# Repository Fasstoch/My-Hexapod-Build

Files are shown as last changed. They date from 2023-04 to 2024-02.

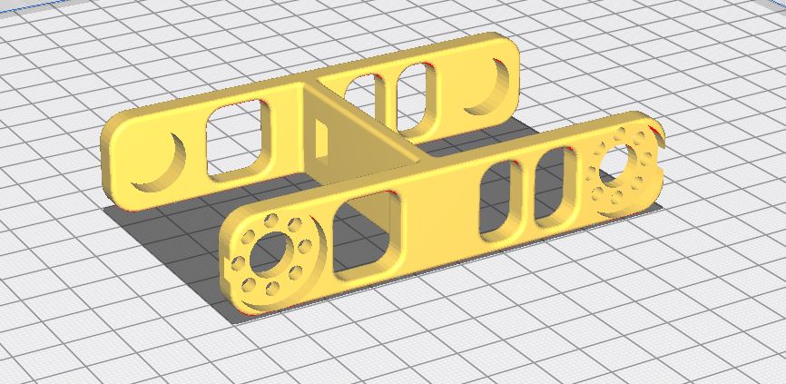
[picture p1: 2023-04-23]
Images/Femur.JPG

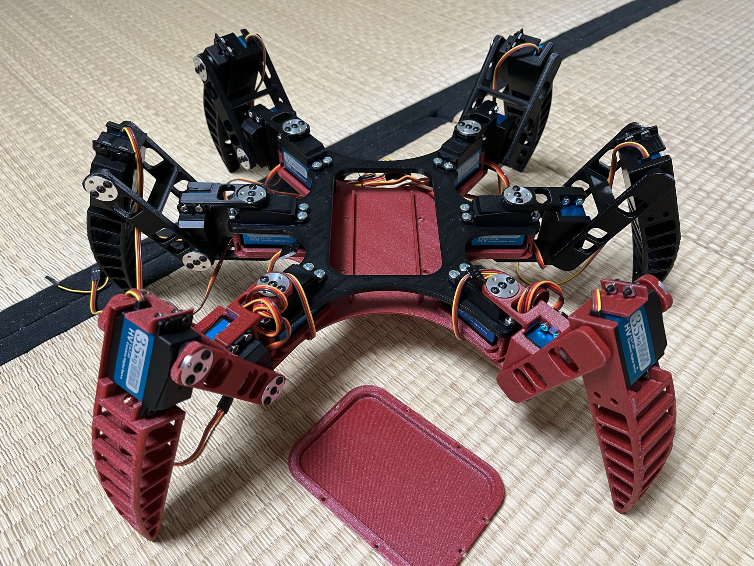
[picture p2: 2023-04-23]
Images/MyPLAHexapod.jpeg

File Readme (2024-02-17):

Readme File :

This 3D design is made to be compliant with standard servo like these : 
https://fr.aliexpress.com/item/1005004291650317.html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

This 3D design is made to be compliant with metal circle horns (25 T Servo / diam 20mm) like these : 
https://fr.aliexpress.com/item/4000600375910.html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

This 3D design is made to be compliant with bearings (4 mm x 13 mm x 5 mm) like these : 
https://www.amazon.fr/dp/B07FXXMN4P?psc=1&ref=ppx_yo2ov_dt_b_product_details

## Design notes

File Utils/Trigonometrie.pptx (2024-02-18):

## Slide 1

hexapod_spiderbot_tutorials (https://github.com/robs-tech-workbench/hexapod_spiderbot_tutorials/blob/main/tutorial_forward_kinematics/media/top_view.png)/ (https://github.com/robs-tech-workbench/hexapod_spiderbot_tutorials/blob/main/tutorial_forward_kinematics/media/top_view.png)tutorial_forward_kinematics (https://github.com/robs-tech-workbench/hexapod_spiderbot_tutorials/blob/main/tutorial_forward_kinematics/media/top_view.png)/media/top_view.png at main · robs-tech- (https://github.com/robs-tech-workbench/hexapod_spiderbot_tutorials/blob/main/tutorial_forward_kinematics/media/top_view.png)workbench (https://github.com/robs-tech-workbench/hexapod_spiderbot_tutorials/blob/main/tutorial_forward_kinematics/media/top_view.png)/ (https://github.com/robs-tech-workbench/hexapod_spiderbot_tutorials/blob/main/tutorial_forward_kinematics/media/top_view.png)hexapod_spiderbot_tutorials (https://github.com/robs-tech-workbench/hexapod_spiderbot_tutorials/blob/main/tutorial_forward_kinematics/media/top_view.png) · GitHub (https://github.com/robs-tech-workbench/hexapod_spiderbot_tutorials/blob/main/tutorial_forward_kinematics/media/top_view.png)

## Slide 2

Top

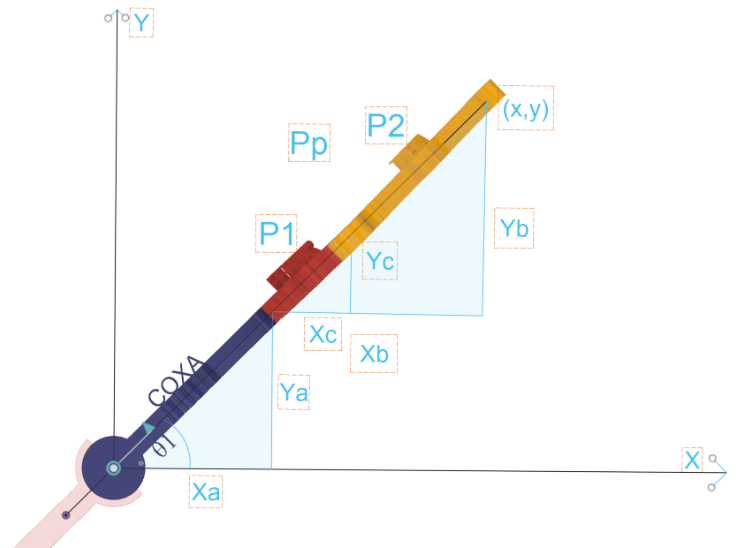
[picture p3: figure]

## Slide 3

Side

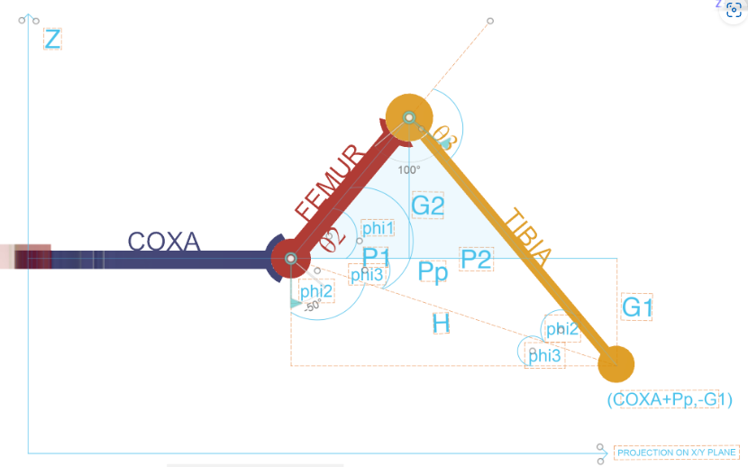
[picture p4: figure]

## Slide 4

3D

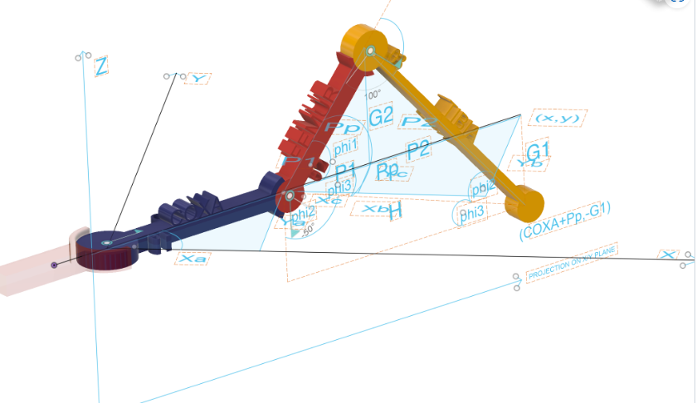
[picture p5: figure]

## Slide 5

sin ( θ )= (opp)/(hyp) θ = arcsin((opp)/(hyp))
cos ( θ )= (adj)/(hyp) θ = arccos((adj)/(hyp))
tan ( θ )= (opp)/(adj) θ = arctan((opp)/(adj))

hyp

opp

θ

adj

A

cos ( C )= (a^2 +b^2 −c^2)/(2 ∗a ∗b)
cos ( A )= (b^2 +c^2 −a^2)/(2 ∗b ∗ c)
cos ( B )= (c^2 +a^2 − b^2)/(2 ∗c ∗a)

C=?

B

C

a

b

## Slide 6

1. Angle Conversion: The method begins by converting the joint angles from degrees to radians. This conversion is essential as trigonometric functions in Python's math library require angles in radians.
theta1, theta2, theta3 = map(math.radians, self.get_angles())
2. Coxa-Femur Joint Calculation:
  - Xa and Ya determine the x and y coordinates of the coxa-femur joint (the hip joint). They are calculated using the cosine and sine of theta1, respectively, multiplied by the length of the coxa (self.COXA). Cosine gives the horizontal component, and sine provides the vertical component.
Xa = self.COXA * math.cos(theta1)
Ya = self.COXA * math.sin(theta1)
3. Femur Segment Calculations:
  - The vertical component G2 of the femur length is calculated by the femur length (self.FEMUR) multiplied by the sine of theta2. This gives the vertical displacement.
  - The horizontal component P1 is found by multiplying the femur length by the cosine of theta2. This gives the horizontal displacement.
G2 = math.sin(theta2) * self.FEMUR
P1 = math.cos(theta2) * self.FEMUR
4. Femur-Tibia Joint Calculation:
  - Xc and Yc are the x and y coordinates of the femur-tibia joint (knee joint), computed by multiplying P1 with the cosine and sine of theta1.
Xc = math.cos(theta1) * P1
Yc = math.sin(theta1) * P1

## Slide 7

5.Tibia-Tip Joint Calculation:
  - This step involves calculating the position of the tibia-tip joint (foot of the leg) using a series of trigonometric calculations.
  - H is the straight-line distance from the femur-tibia joint to the tibia-tip joint, calculated using the Law of Cosines.
H = math.sqrt(self.TIBIA**2 + self.FEMUR**2 - 2*self.TIBIA*self.FEMUR*math.cos(math.radians(180) - theta3))
  - phi1 is calculated using the Law of Cosines again, to find the angle at the femur-tibia joint.
phi1 = math.acos((self.FEMUR**2 + H**2 - self.TIBIA**2) / (2*self.FEMUR*H))
  - phi2 is the angle at the tibia-tip joint. It's calculated by subtracting phi1 and the external angle ( 180^\circ - \theta3 ) from 180 degrees.
  - phi3 is an auxiliary angle, used to find the horizontal and vertical projections. It's calculated by subtracting theta2 from phi1.
phi2 = math.radians(180) - (math.radians(180) - theta3) - phi1
phi3 = phi1 - theta2
  - Pp is the horizontal projection of the tibia-tip joint on the plane of the femur. It is calculated using the cosine of phi3 multiplied by H.
Pp = math.cos(phi3) * H
  - P2 is the horizontal distance between the femur-tibia joint and the tibia-tip joint. It is calculated as the difference between Pp and P1.
P2 = Pp - P1
  - Yb and Xb are the x and y coordinates of the tibia-tip joint, calculated by multiplying the sine and cosine of theta1 by Pp, respectively.
Yb = math.sin(theta1) * Pp
Xb = math.cos(theta1) * Pp
  - G1 is the vertical component (z-coordinate) of the tibia-tip joint. It is calculated using the sine of phi3 multiplied by H. The result is negated as the z-axis might be defined downwards in the robot's coordinate system.
G1 = math.sin(phi3) * H
G1 = -G1
6.Joint Locations List:
  - The method concludes by creating a list of joint locations. Each joint location is represented by a set of x, y, and z coordinates. This list includes the positions of the base joint, coxa-femur joint, femur-tibia joint, and the tip of the leg.
joint_locations = [
[0, 0, 0], # Base joint
[Xa, Ya, 0], # Coxa-femur joint
[Xa + Xc, Ya + Yc, G2], # Femur-tibia joint
[Xa + Xb, Ya + Yb, G1] # Tip of the leg
]

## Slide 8

sin ( θ )= (opp)/(hyp) θ = arcsin((opp)/(hyp))
cos ( θ )= (adj)/(hyp) θ = arccos((adj)/(hyp))
tan ( θ )= (opp)/(adj) θ = arctan((opp)/(adj))

hyp

opp

θ

adj

A

cos ( C )= (a^2 +b^2 −c^2)/(2 ∗a ∗b) C =arccos ((a^2 +b^2 −c^2)/(2 ∗a ∗b) )
cos ( A )= (b^2 +c^2 −a^2)/(2 ∗b ∗ c)
cos ( B )= (c^2 +a^2 − b^2)/(2 ∗c ∗a)

C=?

B

C

a

b

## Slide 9

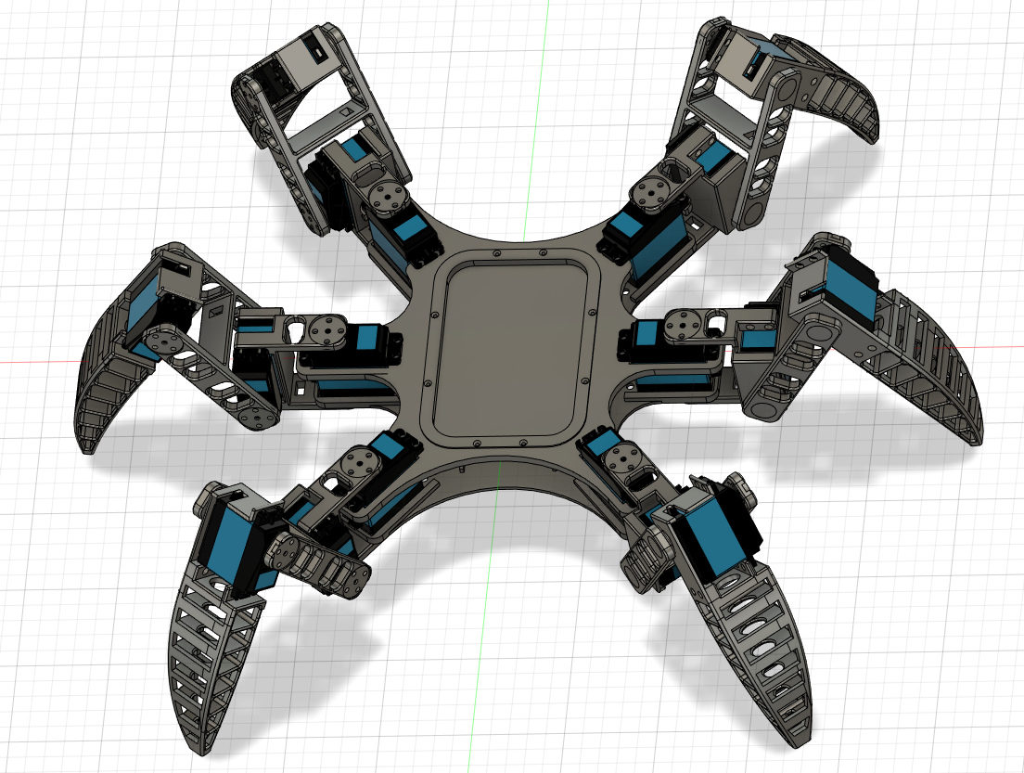
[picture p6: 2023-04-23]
Images/Fusion360View.png

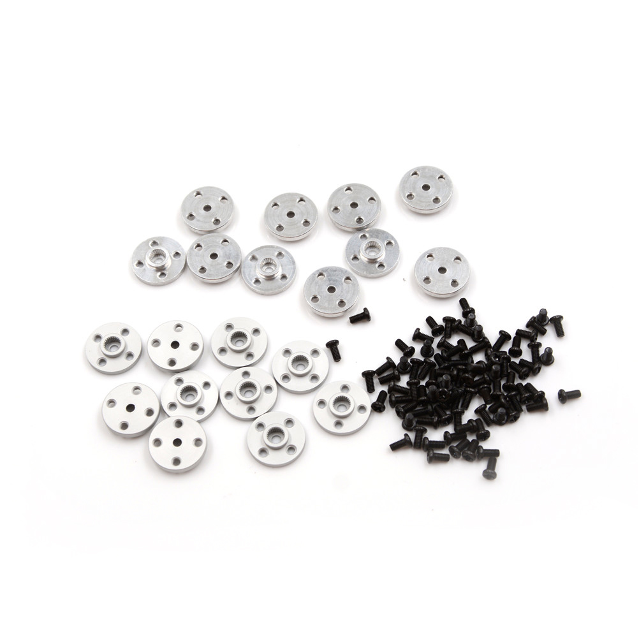
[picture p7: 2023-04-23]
Circle_metal_horn.jpg

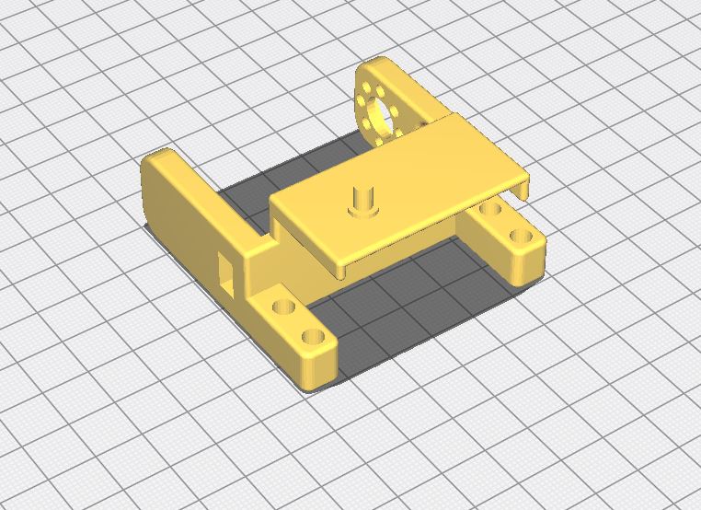
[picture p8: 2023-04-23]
Images/Coxa.JPG

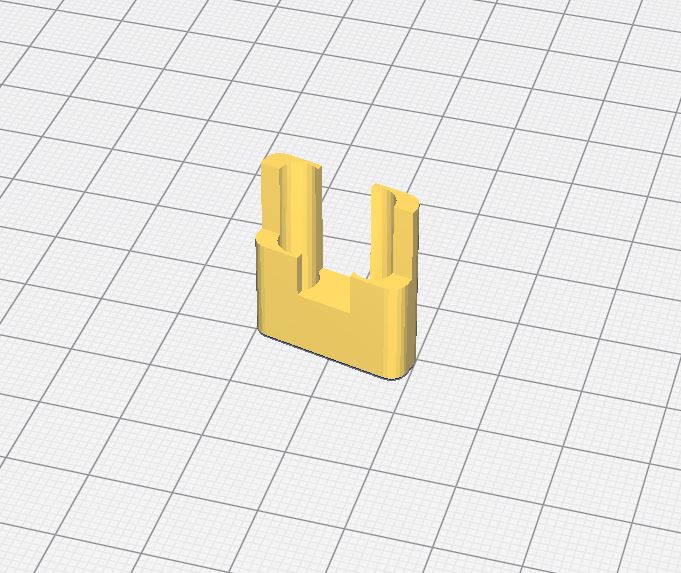
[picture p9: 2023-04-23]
Images/Spacer2.JPG

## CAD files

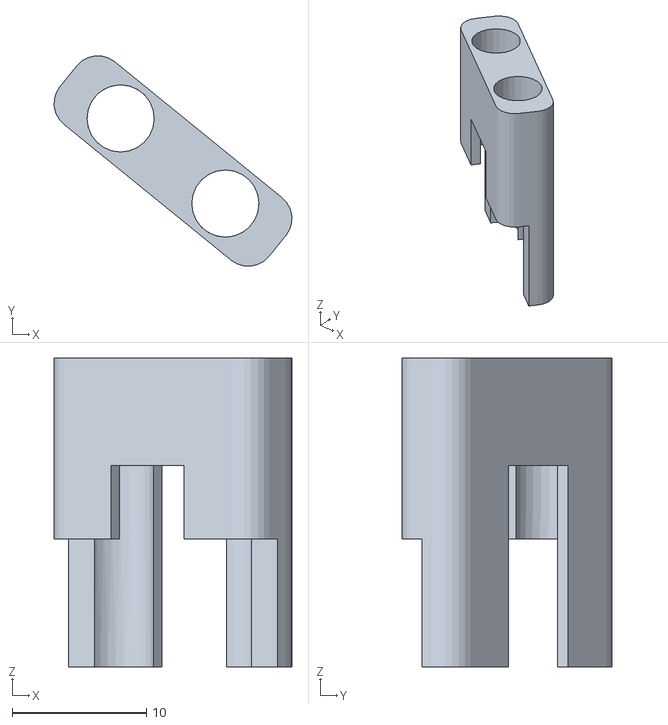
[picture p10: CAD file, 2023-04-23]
STL/Hexapod Reboot Spacer2.stl
17.7 x 15.7 x 23.0

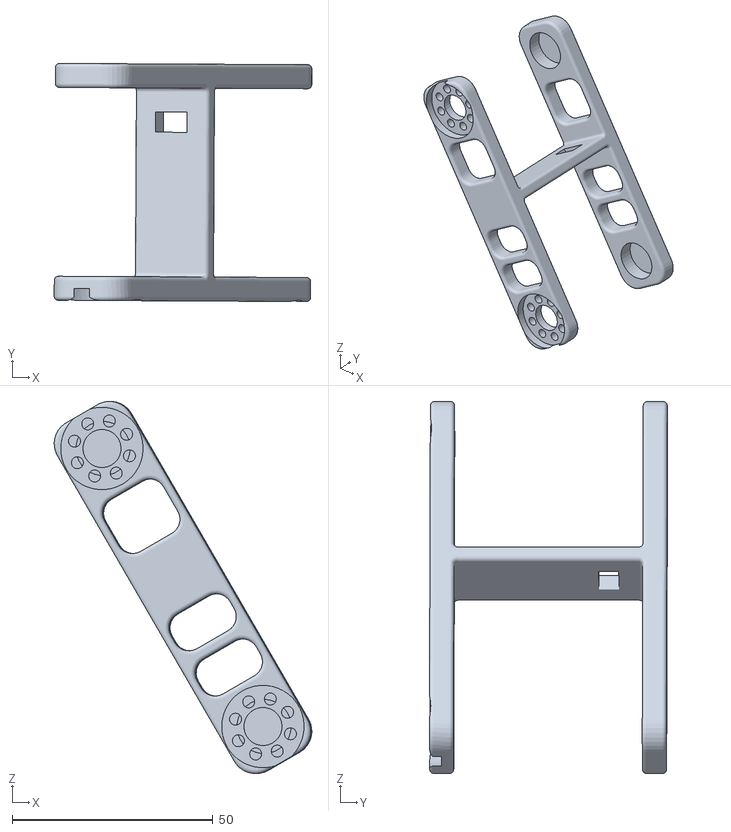
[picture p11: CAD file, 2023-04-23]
STL/Hexapod Reboot Femur.stl
64.2 x 59.3 x 92.6

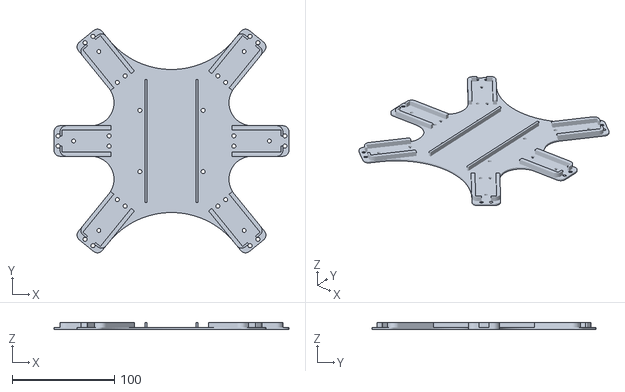
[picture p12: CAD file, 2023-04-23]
STL/Hexapod Reboot Body bottom.stl
230.0 x 218.9 x 7.00

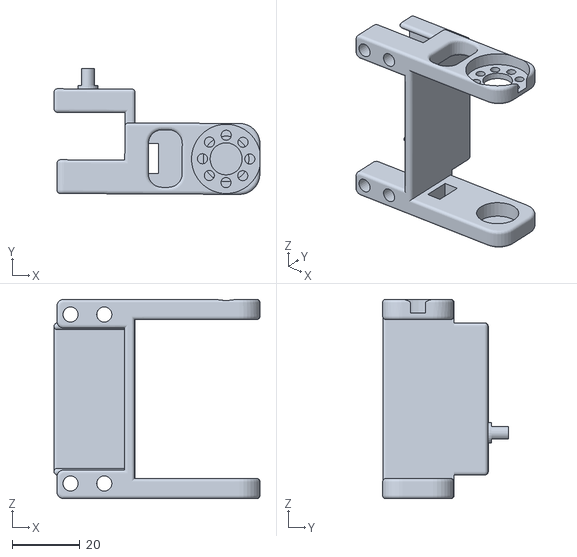
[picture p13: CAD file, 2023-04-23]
STL/Hexapod Reboot Coxa.stl
60.9 x 37.2 x 59.0

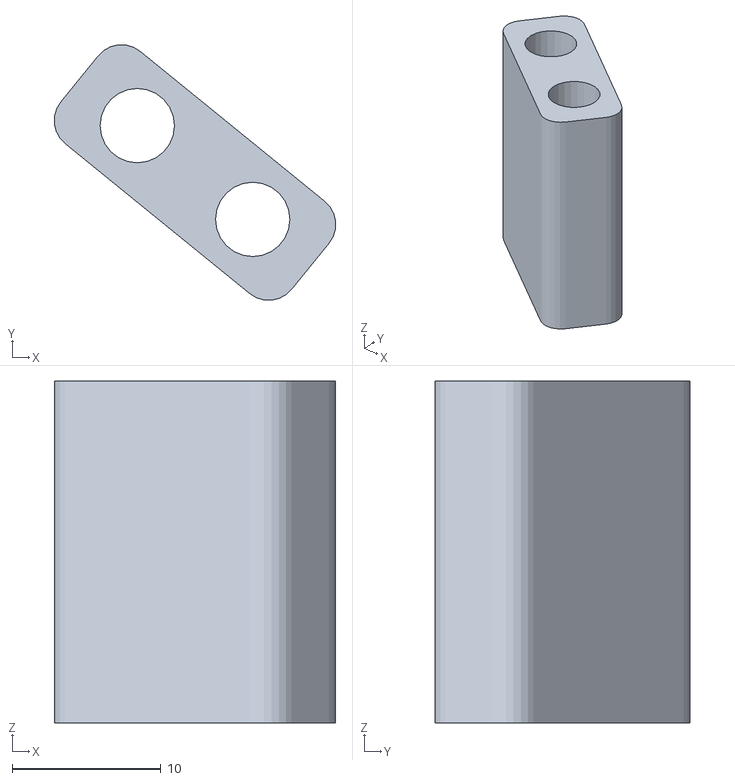
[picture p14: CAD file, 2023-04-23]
STL/Hexapod Reboot Spacer.stl
18.9 x 17.2 x 23.0

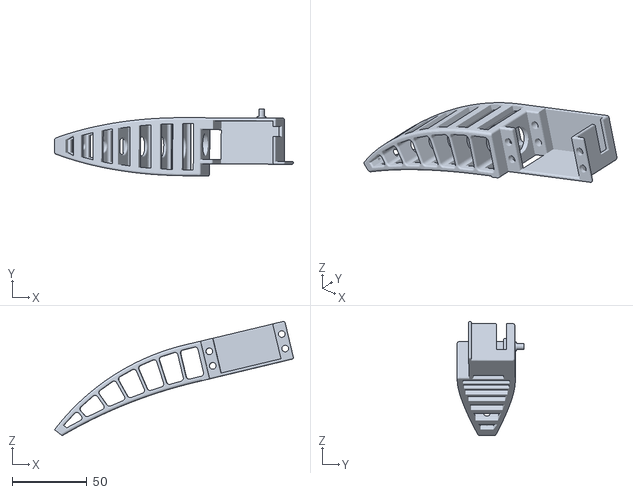
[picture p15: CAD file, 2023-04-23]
STL/Hexapod Reboot Tibia.stl
160.3 x 44.8 x 76.6

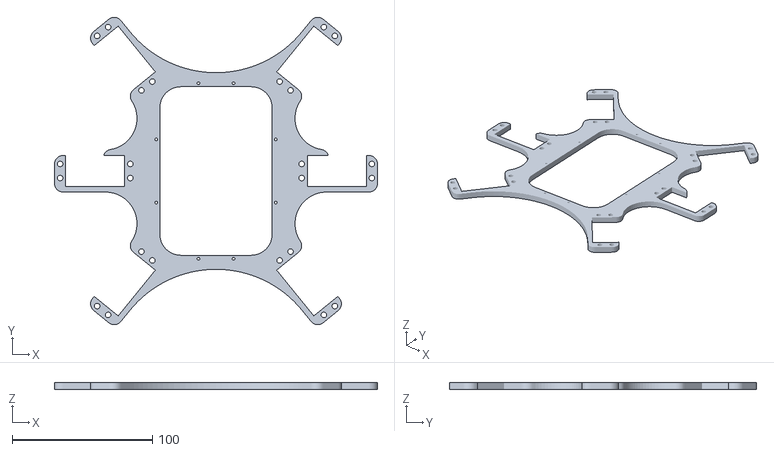
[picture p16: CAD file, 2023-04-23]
STL/Hexapod Reboot Body Top.stl
230.0 x 218.9 x 5.00

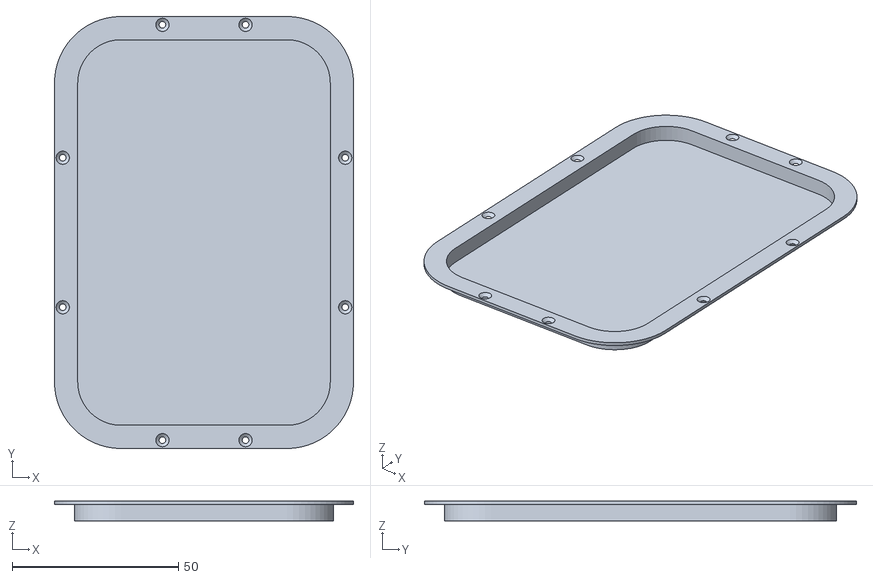
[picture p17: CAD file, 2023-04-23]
STL/Hexapod Reboot Support elec.stl
90.0 x 130.0 x 6.00

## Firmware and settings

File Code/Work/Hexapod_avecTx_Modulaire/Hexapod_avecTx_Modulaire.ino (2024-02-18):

// Appuie Gauche de la télécommande permet de switcher entre la position initiale et la position cible

#include "espNowCommunication.h"
#include "ServoConfig.h"
#include "ServoFunctions.h"
#include "gestionEtat.h"
#include "Angles.h"

void setup() {
  // Initialisation
  Serial.begin(115200);
  initialiserESPNow(); // défini dans "espNowCommunication.h", pour établir la communication avec l'ESP32 de la télécommande
  
  setupServos(); // défini dans "ServoConfig.h", pour initialiser les PIN, les SERVOMIN et SERVOMAX
  MoveLegInit(); // défini dans "ServoFunctions.h"

}

void loop() {
  gestionEtat(); // défini dans "gestionEtat.h"
  //delay(50);

}

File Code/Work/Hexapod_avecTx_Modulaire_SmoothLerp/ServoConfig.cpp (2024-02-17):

#include "ServoConfig.h"

Adafruit_PWMServoDriver board_left = Adafruit_PWMServoDriver(0x40);
Adafruit_PWMServoDriver board_right = Adafruit_PWMServoDriver(0x41);

// Define servos ports
uint8_t LegRF[3] = {15, 14, 13}; // Leg Right Front (0-180): Coxa(forward-backward) Femur(up-down) Tibia(down-up)
uint8_t LegR[3] = {10, 9, 8}; // Leg Right  (0-180): Coxa(forward-backward) Femur(up-down) Tibia(down-up)
uint8_t LegRB[3] = {2, 1, 0}; // Leg Right Back (0-180): Coxa(forward-backward) Femur(up-down) Tibia(down-up
uint8_t LegLF[3] = {0, 1, 2}; // Leg Left Front (0-180): Coxa(forward-backward) Femur(up-down) Tibia(down-up)
uint8_t LegL[3] = {5, 6, 7}; // Leg Left  (0-180): Coxa(forward-backward) Femur(up-down) Tibia(down-up)
uint8_t LegLB[3] = {13, 14, 15}; // Leg Left Back (0-180): Coxa(forward-backward) Femur(up-down) Tibia(down-up)

// Define servos MIN and MAX positions
int LegRF_SERVOMIN[3] = {160,210,150}; // Leg Right Front : Coxa, Femur, Tibia / 'minimum' pulse length count (out of 4096)
int LegRF_SERVOMAX[3] = {640,560,410}; // Leg Right Front : Coxa, Femur, Tibia / 'maximum' pulse length count (out of 4096)
int LegR_SERVOMIN[3] = {170,210,120}; // Leg Rightft : Coxa, Femur, Tibia / 'minimum' pulse length count (out of 4096)
int LegR_SERVOMAX[3] = {610,560,380}; // Leg Right : Coxa, Femur, Tibia / 'maximum' pulse length count (out of 4096)
int LegRB_SERVOMIN[3] = {180,230,100}; // Leg Right Back : Coxa, Femur, Tibia / 'minimum' pulse length count (out of 4096)
int LegRB_SERVOMAX[3] = {610,580,370}; // Leg Right Back : Coxa, Femur, Tibia / 'maximum' pulse length count (out of 4096)
int LegLF_SERVOMIN[3] = {150,215,120}; // Leg Left Front : Coxa, Femur, Tibia / 'minimum' pulse length count (out of 4096)
int LegLF_SERVOMAX[3] = {650,570,400}; // Leg Left Front : Coxa, Femur, Tibia / 'maximum' pulse length count (out of 4096)
int LegL_SERVOMIN[3] = {250,205,120}; // Leg Left : Coxa, Femur, Tibia / 'minimum' pulse length count (out of 4096)
int LegL_SERVOMAX[3] = {600,560,400}; // Leg Left : Coxa, Femur, Tibia / 'maximum' pulse length count (out of 4096)
int LegLB_SERVOMIN[3] = {130,205,130}; // Leg Left Back : Coxa, Femur, Tibia / 'minimum' pulse length count (out of 4096)
int LegLB_SERVOMAX[3] = {590,570,410}; // Leg Left Back : Coxa, Femur, Tibia / 'maximum' pulse length count (out of 4096)


void setupServos() {
  board_right.begin();
  board_left.begin();
  board_right.setPWMFreq(60);
  board_left.setPWMFreq(60);
}

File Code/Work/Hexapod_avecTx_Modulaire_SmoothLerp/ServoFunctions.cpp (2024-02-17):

#include "ServoFunctions.h"
#include "Angles.h"

float t = 0.0;

int angleToPulse(int ang, int SERVOMIN, int SERVOMAX) {
  int pulse = map(ang,0,180,SERVOMIN,SERVOMAX);
  return pulse;
}

void MoveLegInit(){
  for (int i=0; i<3; i++){
    board_right.setPWM(LegRF[i], 0, angleToPulse(initAngles[i], LegRF_SERVOMIN[i], LegRF_SERVOMAX[i]) );
    board_right.setPWM(LegR[i], 0, angleToPulse(initAngles[i], LegR_SERVOMIN[i], LegR_SERVOMAX[i]) );
    board_right.setPWM(LegRB[i], 0, angleToPulse(initAngles[i], LegRB_SERVOMIN[i], LegRB_SERVOMAX[i]) );
    board_left.setPWM(LegLF[i], 0, angleToPulse(initAngles[i], LegLF_SERVOMIN[i], LegLF_SERVOMAX[i]) );
    board_left.setPWM(LegL[i], 0, angleToPulse(initAngles[i], LegL_SERVOMIN[i], LegL_SERVOMAX[i]) );
    board_left.setPWM(LegLB[i], 0, angleToPulse(initAngles[i], LegLB_SERVOMIN[i], LegLB_SERVOMAX[i]) );
  }
}

/*
void MoveLeg(uint8_t Leg[3], int angle[3], int SERVOMIN[3], int SERVOMAX[3]) {
  for (int i=0; i<3; i++){
    board_right.setPWM(Leg[i], 0, angleToPulse(angle[i], LegRF_SERVOMIN[i], LegRF_SERVOMAX[i]) );
  }*/
void MoveLeg(uint8_t Leg[3], int angle[3], int SERVOMIN[3], int SERVOMAX[3]) {
  if (t < 1.0) t += 0.02;
  
  int smoothedAngles[3]; // Stocker les angles lissés
  // Lissage linéaire pour chaque angle
  for (int i = 0; i < 3; i++) {
      // Utilisation de l'interpolation lerp pour lisser les angles
      smoothedAngles[i] = lerp(currentAngles[i], angle[i], t);
  }

  for (int i = 0; i < 3; i++) {
      board_right.setPWM(Leg[i], 0, angleToPulse(smoothedAngles[i], SERVOMIN[i], SERVOMAX[i]));
    }
      
    // Attendre un court laps de temps pour la transition douce
    delay(20);

  // Copie des valeurs de angle dans CurrentAngles
  for (int i = 0; i < 3; i++) {
      currentAngles[i] = angle[i];
  }
}

void MoveLegbis(uint8_t Leg[3], int angle[3], int SERVOMIN[3], int SERVOMAX[3]) {
  for (float t = 0.0; t <= 1.0; t += 0.02) { // Variation progressive de t de 0 à 1
    int smoothedAngles[3]; // Stocker les angles lissés
    
    // Lissage linéaire pour chaque angle
    for (int i = 0; i < 3; i++) {
      // Utilisation de l'interpolation lerp pour lisser les angles
      smoothedAngles[i] = lerp(currentAngles[i], angle[i], t);
    }
    
    // Appliquer les angles lissés aux servomoteurs
    for (int i = 0; i < 3; i++) {
      board_right.setPWM(Leg[i], 0, angleToPulse(smoothedAngles[i], SERVOMIN[i], SERVOMAX[i]));
    }
    
    // Attendre un court laps de temps pour la transition douce
    delay(20);
  }

  // Copie des valeurs de angle dans CurrentAngles
  for (int i = 0; i < 3; i++) {
      currentAngles[i] = angle[i];
  }
}


// Fonction lerp pour l'interpolation linéaire
float lerp(float a, float b, float t) {
  return a + t * (b - a);
}

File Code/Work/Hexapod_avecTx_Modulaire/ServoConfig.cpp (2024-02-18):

#include "ServoConfig.h"

Adafruit_PWMServoDriver board_left = Adafruit_PWMServoDriver(0x40);
Adafruit_PWMServoDriver board_right = Adafruit_PWMServoDriver(0x41);

// Define servos ports
int Leg[6][3] = {
    {15, 14, 13},   // Leg Right Front
    {10, 9, 8},     // Leg Right
    {2, 1, 0},      // Leg Right Back
    {0, 1, 2},      // Leg Left Front
    {5, 6, 7},      // Leg Left
    {13, 14, 15}    // Leg Left Back
};

// Define servos MIN and MAX positions
int Leg_SERVOMIN[6][3] = {
    {160, 210, 150},    // Leg Right Front
    {170, 210, 120},    // Leg Right
    {180, 230, 100},    // Leg Right Back
    {150, 215, 120},    // Leg Left Front
    {250, 205, 120},    // Leg Left
    {130, 205, 130}     // Leg Left Back
};

int Leg_SERVOMAX[6][3] = {
    {640, 560, 410},    // Leg Right Front
    {610, 560, 380},    // Leg Right
    {610, 580, 370},    // Leg Right Back
    {650, 570, 400},    // Leg Left Front
    {600, 560, 400},    // Leg Left
    {590, 570, 410}     // Leg Left Back
};

void setupServos() {
  board_right.begin();
  board_left.begin();
  board_right.setPWMFreq(60);
  board_left.setPWMFreq(60);
}

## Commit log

2023-04-23 My Hexapod files
    [Hexapod Reboot Body Top.stl, Hexapod Reboot Body bottom.stl, Hexapod Reboot Coxa.stl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]
2024-02-17 Dev Work
    Ajout des devs en cours
2024-02-18 Leg simplifé
    uniformisation du code pour chaque Leg
2024-02-18 Fichiers utiles
    Ajout fichiers utiles
    [Calcul IK_2.xlsx]
